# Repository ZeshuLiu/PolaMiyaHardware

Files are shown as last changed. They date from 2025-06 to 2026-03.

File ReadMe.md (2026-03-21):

# PolaMiyaHardware - 宝丽来相机改装项目

宝丽来相机自动化改装项目的机械与电路设计部分。

> 完整项目：https://github.com/ZeshuLiu/PolaMiya
> 软件固件仓库：https://github.com/ZeshuLiu/PolaMiyaSoftware

## 仓库结构

| 子目录 | 说明 |
|---|---|
| [电路/](电路/) | KiCad 电路设计 |
| [结构 Rev2N/](结构 Rev2N/) | 机械结构 3D 模型 (STL/STP) |

### 电路设计

| 模块 | 说明 |
|---|---|
| [主控器](电路/主控器/PM_Controller_R1/) | 主控制器 (STM32G474) |
| [DispKey](电路/主控器/DispKey/) | 屏幕与按键模块 |
| [电机驱动](电路/电机驱动/MotroDrive/) | 吐片电机驱动板 |
| [闪光灯转接](电路/闪光灯转接/FlashAdapter/) | 闪光灯转接板 |

> 所有 PCB 使用 **KiCad 9** 绘制，Gerber 文件和 BOM 清单位于各模块的 `production/` 子目录中。

### 结构设计

| 组件 | 说明 |
|---|---|
| 镜头总成 | Mamiya Press 127mm 镜头安装座 |
| 片仓总成 | 宝丽来相纸仓 |
| 吐片机构 | 电动吐片下巴与齿轮组 |
| 外壳 | 相机主体外壳 |
| 全息取景器 | 计划中的升级部件 |

> 所有 STL 文件位于各组件的 `STL/` 子目录中，可用 A1 mini 或 Voron0 等小型 3D 打印机打印。

## 技术栈

| 类别 | 工具/平台 |
|---|---|
| **PCB 设计** | KiCad 9 |
| **结构设计** | SolidWorks / 兼容 CAD 软件 |
| **固件** | STM32CubeMX + HAL 库，Keil MDK-ARM |
| **3D 打印** | PLA/PETG，A1 mini / Voron0 |

## 采购清单

主要采购件：
- Mamiya Press 127mm 镜头（不需要调焦桶）
- 宝丽来 AF5000（用于拆解吐片下巴、吐片电机和齿轮组）

## 使用方法

### 相机操作
- **开机/关机**：长按机身左下角按钮 2 秒
- **吐片**：三向按钮长按中键 2 秒启动吐片电机，短按中键停止，随后推动侧面推杆吐出相纸
- **测距**：开机即运行

### 功能
- ✅ 电动吐片
- ✅ 电子测距
- 🔄 自动对焦（计划中）
- 🔄 测光（计划中）
- 🔄 全息取景器（计划中）

## 已知问题

| 问题 | 状态 |
|---|---|
| 吐片口密封性能不好，严禁在有相纸的情况下打开片仓 | 使用中注意 |

## 已修复问题

| 问题 | 修复版本 |
|---|---|
| 吐片电机运行导致测距停止（硬件干扰） | Rev1.2 |
| 温度传感器位置不合理，受芯片发热影响大 | Rev1.2 |

## 相关资源

- [样片与演示]() - 待更新
- [装配指南](结构 Rev2N/) - 参考总装配 STEP 文件

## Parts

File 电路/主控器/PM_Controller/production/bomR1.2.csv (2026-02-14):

Designator | Footprint | Quantity | Value | LCSC Part #
BT1 | cr1220 | 1 | Battery_Cell
C1, C2, C25, C3 | 603 | 4 | 5pf
C10, C32, C34, C35 | 603 | 4 | 1uf
C11, C38, C5, C6 | CP_EIA-3528-21_Kemet-B_Pad1.50x2.35mm_HandSolder | 4 | 22uf
C12 | 1206 | 1 | 22uf
C14, C24 | CP_EIA-3528-21_Kemet-B_Pad1.50x2.35mm_HandSolder | 2 | 47uf
C17, C18, C19, C20 | 603 | 4 | 22uf
C21, C23, C26, C28, C29, C30, C31, C33, C36, C37, C4, C7 | 603 | 12 | 100nf
C22, C27, C8 | 603 | 3 | 10uf
C39 | CP_EIA-3528-21_Kemet-B_HandSolder | 1 | 22uf
C40 | 1206 | 1 | 1uf
C41 | 1206 | 1 | 10uf
CHG1, PW_LED1 | 805 | 2 | LED
D1 | D_SMA | 1 | SS34
D3 | D_SMA_Handsoldering | 1 | SS32
D4 | D_SOD-323_HandSoldering | 1 | 1N5819WS
FB1 | 805 | 1 | FerriteBead
FLASH1 | SolderWire-0.1sqmm_1x02_P3.6mm_D0.4mm_OD1mm_Relief | 1 | Conn_01x02_Pin
J1, J4 | JST_PH_S4B-PH-K_1x04_P2.00mm_Horizontal | 2 | Conn_01x04_Socket
J10, J7 | PinHeader_2x04_P1.27mm_Vertical | 2 | Conn_02x04_Odd_Even
J11 | PinHeader_2x06_P1.27mm_Vertical | 1 | Conn_02x06_Odd_Even
J2, J3, J9 | PinHeader_1x04_P2.54mm_Vertical | 3 | Conn_01x04_Socket
J5 | SolderWire-0.5sqmm_1x02_P4.8mm_D0.9mm_OD2.3mm | 1 | Conn_01x02_Pin
J6 | PinSocket_1x02_P2.00mm_Vertical | 1 | Conn_01x02_Pin
J8 | PinHeader_1x04_P2.00mm_Vertical | 1 | Conn_01x04_Pin
L1, L2, L3 | L_APV_APH0650 | 3 | 4.7uH
Q2, Q3, Q5, Q6 | SOT-23 | 4 | AO3400A
R1, R12, R14, R15, R2, R23, R24, R27, R28, R31, R39, R41, R42, R8 | 603 | 14 | 100k
R13, R4 | 603 | 2 | 1.5k
R16, R17, R18, R20, R21, R22 | 603 | 6 | 100k(NC)
R25, R26, R32, R40, R6 | 603 | 5 | 1k
R29, R33, R34, R35, R36, R45, R7 | 603 | 7 | 10k
R3 | 603 | 1 | RPORG(1k)
R30, R38, R43 | 603 | 3 | 150k
R37, R5 | 603 | 2 | 22k
R44 | 603 | 1 | 33k
U1, U9 | SOIC-8_3.9x4.9mm_P1.27mm | 2 | AT24CS08-SSHM
U10 | SOT-563 | 1 | TMP102xxDRL
U11, U6 | DBV0006A_TEX | 2 | TPS2552DDBVR
U12 | MFSOP6-4_4.4x3.6mm_P1.27mm | 1 | TLP127
U13 | SOT-23-6_DBV_TEX | 1 | TLV61048DBVR
U2 | SOT-223-3_TabPin2 | 1 | AMS1117-3.3
U3 | LQFP-64_10x10mm_P0.5mm | 1 | STM32G431RBTx
U5 | SOT-23-6_Handsoldering | 1 | BQ21040DBV
U7 | TSSOP-14_4.4x5mm_P0.65mm | 1 | STM32L011D4Px
U8 | SOT-23-5_HandSoldering | 1 | ME6211C25M5
Y1 | Crystal_C26-LF_D2.1mm_L6.5mm_Horizontal | 1 | 32.768kHz
Y2 | Crystal_DS26_D2.0mm_L6.0mm_Horizontal | 1 | 24Mhz

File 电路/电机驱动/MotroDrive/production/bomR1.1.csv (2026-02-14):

Designator | Footprint | Quantity | Value | LCSC Part #
C1 | 1206 | 1 | 10uf
C2 | 1206 | 1 | 1uf
C4 | CP_Elec_6.3x7.7 | 1 | 100uf
D1, D4 | D_SOD-323_HandSoldering | 2 | 1N5819WS
D3 | 805 | 1 | LED
FB1 | 603 | 1 | FerriteBead
J1 | JST_PH_S4B-PH-SM4-TB_1x04-1MP_P2.00mm_Horizontal | 1 | Conn_01x04_MountingPin
J2 | JST_PH_S2B-PH-SM4-TB_1x02-1MP_P2.00mm_Horizontal | 1 | Conn_01x02_MountingPin
L2 | L_APV_APH1265 | 1 | 4.7uH
Q1 | SOT-23 | 1 | AO3400A
R1 | 603 | 1 | 330k
R2 | 603 | 1 | 51k
R4 | 603 | 1 | 10k
R5 | 603 | 1 | 1k
U1 | SOT-23-6_DBV_TEX | 1 | TLV61048DBVR

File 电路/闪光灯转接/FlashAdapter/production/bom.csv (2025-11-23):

Designator | Footprint | Quantity | Value | LCSC Part #
J1 | SolderWire-0.75sqmm_1x02_P7mm_D1.25mm_OD3.5mm | 1 | Conn_01x02_Socket
U1 | PJ-218X-SMT | 1 | ~

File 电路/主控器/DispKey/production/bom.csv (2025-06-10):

Designator | Footprint | Quantity | Value | LCSC Part #
C1, C2 | 0805 | 2 | 10uf
C10, C11, C12 | 0603 | 3 | 1uF
D1, D2 | 0805 | 2 | LED
J1 | SolderWire-0.1sqmm_1x02_P3.6mm_D0.4mm_OD1mm | 1 | Conn_01x02_Pin
J10, J7 | PinHeader_2x04_P1.27mm_Vertical | 2 | Conn_02x04_Odd_Even
J2 | SolderWire-0.1sqmm_1x03_P3.6mm_D0.4mm_OD1mm | 1 | Conn_01x03_Pin
LCD1 | LCD1.69_240_280 | 1 | ~
R1 | 0603 | 1 | 10k
R11, R12, R13 | 0603 | 3 | 100k
SW1 | sw_push_5.8x5.8mm | 1 | ~
SW3 | Direction3 Pin5 | 1 | ~
TP1 | TestPoint_Pad_2.0x2.0mm | 1 | KEY3

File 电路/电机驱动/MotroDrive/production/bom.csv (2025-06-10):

Designator | Footprint | Quantity | Value | LCSC Part #
C1 | 1206 | 1 | 10uf
C2 | 1206 | 1 | 1uf
C3, C4 | CP_Elec_6.3x7.7 | 2 | 100uf
D1, D4 | D_SOD-323_HandSoldering | 2 | 1N5819WS
D2, D3 | 0805 | 2 | LED
J1 | JST_PH_S4B-PH-SM4-TB_1x04-1MP_P2.00mm_Horizontal | 1 | Conn_01x04_MountingPin
J2 | JST_PH_S2B-PH-SM4-TB_1x02-1MP_P2.00mm_Horizontal | 1 | Conn_01x02_MountingPin
L2 | L_APV_APH1265 | 1 | 4.7uH
R1 | 0603 | 1 | 330k
R2 | 0603 | 1 | 51k
R3, R4 | 0603 | 2 | 10k
U1 | SOT-23-6_DBV_TEX | 1 | TLV61048DBVR

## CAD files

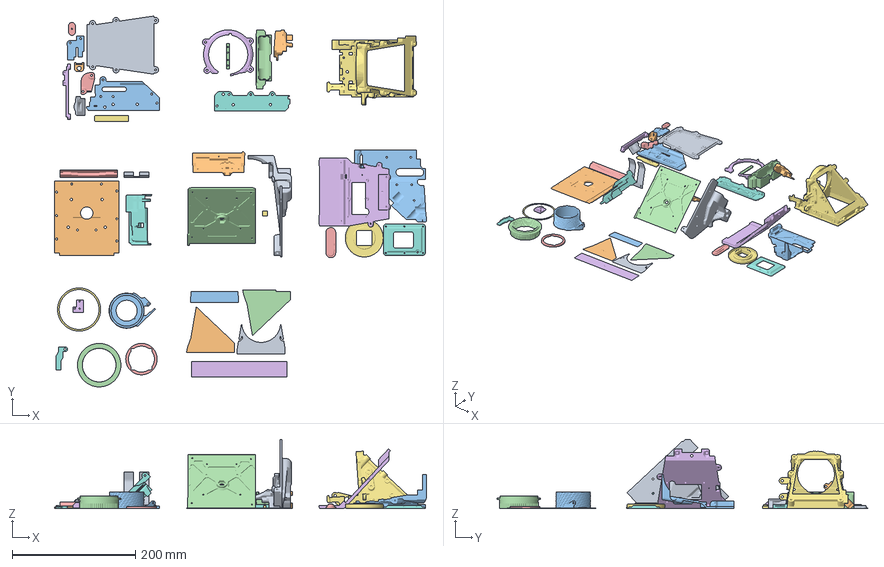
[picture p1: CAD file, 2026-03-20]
结构Rev2N/PolaMiya_FullAssemble.3mf
602.8 x 600.9 x 112.5 mm
反光镜盖板.STL
前左盖.STL
右侧板.STL
后侧板.STL
齿轮盖.STL
调焦桶盖.STL
出片推杆.STL
左侧板.STL
齿轮维护盖.STL
电机卡环.STL
推杆外框.STL
推片钩衬垫.STL
推片把手.STL
电池压板.STL
主片仓.STL
前盖板.STL
片仓弹簧.STL
底板.STL
右侧壳.STL
底壳.STL
推片杆外罩.STL
背壳.STL
镜头挡光板.STL
屏幕盖.STL
左侧壳.STL
顶壳.STL
MamiyaPressLensSeat.STL
内环.STL
挡板.STL
滑块连接.STL
镜头衬垫.STL
闪光灯线.STL
前侧.STL
右内壁.STL
后侧.STL
左内壁.STL
齿轮定位.STL
镜筒.STL
按钮.STL

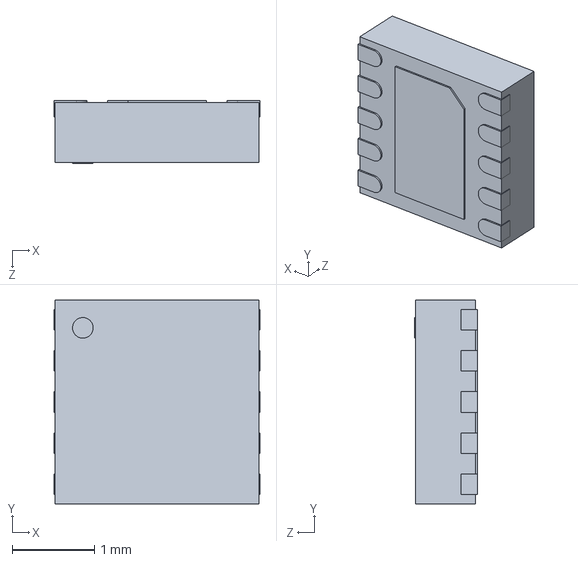
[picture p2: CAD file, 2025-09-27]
结构Rev2N/电路/机身主控/CQ assembly.SLDPRT
2.50 x 2.47 x 0.76 mm

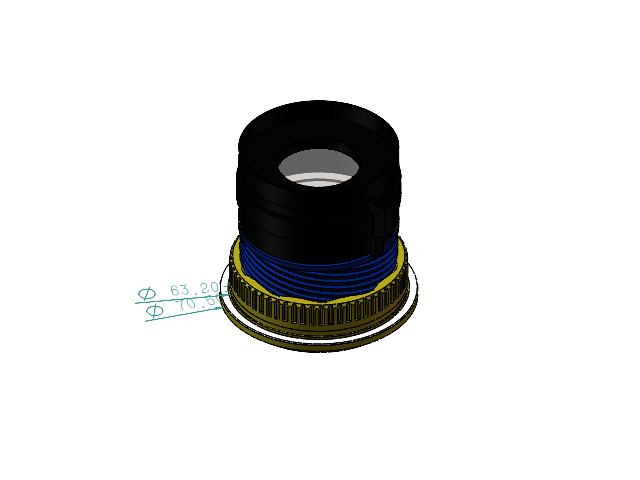
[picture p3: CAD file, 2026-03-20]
结构Rev2N/镜头总成/镜头总成.SLDASM
内环
MamiyaPressLensSeat
滑块连接
MamiyaPress127
MGN7C
镜头衬垫

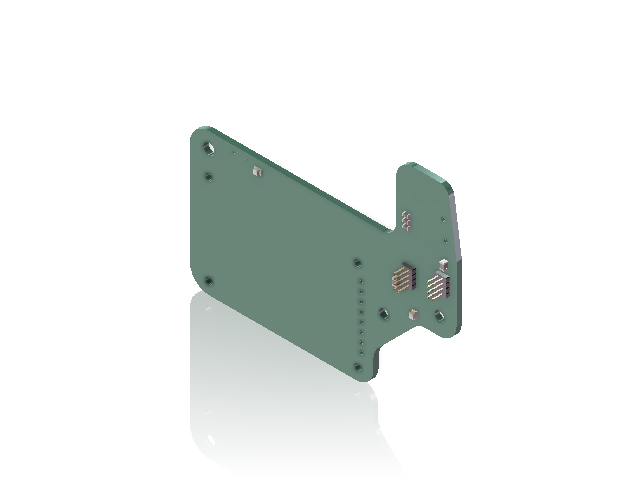
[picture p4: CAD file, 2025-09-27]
结构Rev2N/电路/DispKey_R1_0/DispKey_Screen_R1_0.SLDASM
LED_0805_2012Metric x 2
C_0805_2012Metric x 2
C_0603_1608Metric x 3
PinHeader_2x04_P1.27mm_Vertical x 2
R_0603_1608Metric x 4
DispKey_PCB

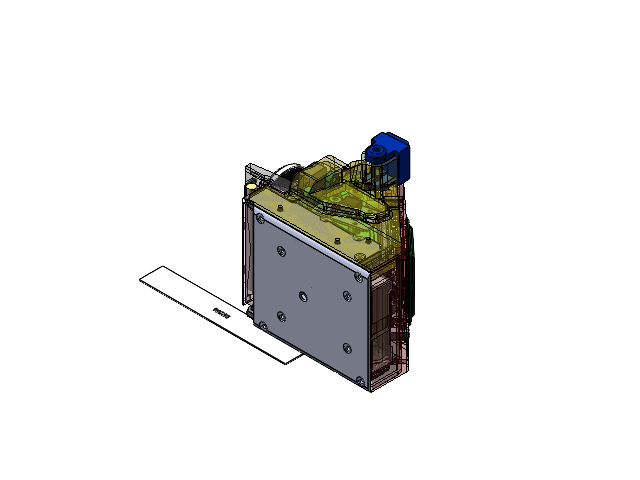
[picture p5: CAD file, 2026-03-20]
结构Rev2N/装配.SLDASM
主片仓
主反射镜
相纸盒
吐片口机身钣金-拆机
MG825-拆机
1.6x20.6-拆机
齿轮A-拆机
1.6x14.6-拆机
齿轮B-拆机
齿轮C-拆机
齿轮D-拆机
齿轮E-拆机
PinHeader_2x04_P1.27mm_Vertical.step x 2
R_0603_1608Metric.step x 42
C_0603_1608Metric.step x 30
SOT-23.step x 6
LQFP-64_10x10mm_P0.5mm.step
PinHeader_1x04_P2.00mm_Vertical.step
PinHeader_2x06_P1.27mm_Vertical.step
CP_EIA-3528-21_Kemet-B.step x 8
PinHeader_1x04_P2.54mm_Vertical.step x 3
LED_0805_2012Metric.step x 2
SOIC-8_3.9x4.9mm_P1.27mm.step x 2
SOT-23-6.step
JST_PH_S4B-PH-K_1x04_P2.00mm_Horizontal.step x 2
D_SMA.step x 3
SOT-563.step
Crystal_C26-LF_D2.1mm_L6.5mm_Horizontal.step x 3
SOT-223.step
PinSocket_1x02_P2.00mm_Vertical.step
L_APV_ANR5040.step
VSSOP-8_3x3mm_P0.65mm.step
TSSOP-14_4.4x5mm_P0.65mm.step
SOT-23-5.step
MFSOP6-4_4.4x3.6mm_P1.27mm.step
L_0805_2012Metric.step
PM_Controller_PCB.step
反光镜盖板
推片勾
MGN7导轨1
调焦桶盖
出片推杆
推片把手
齿轮盖
推片钩衬垫
电机卡环
齿轮维护盖
右侧板
18650电池
后侧板
电池负极弹片
电池正极弹片
激光测距SDM18
D_SOD_323.step x 2
CP_Elec_63x77.step x 2
C_1206_3216Metric-0.step x 2
R_0603_1608Metric-1.step x 4
LED_0805_2012Metric-2.step x 2
L_APV_APH1265-3.step
_autosave-MotroDrive_PCB.step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

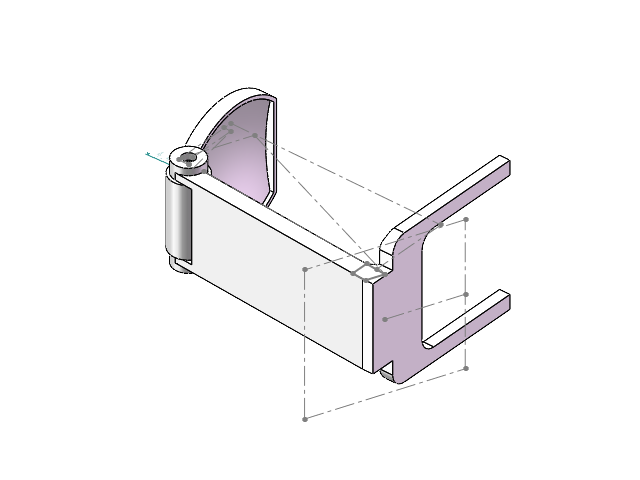
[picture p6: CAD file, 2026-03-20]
结构Rev2N/全息取景器/瞄准装置.SLDASM
主座
镜座
反射镜片

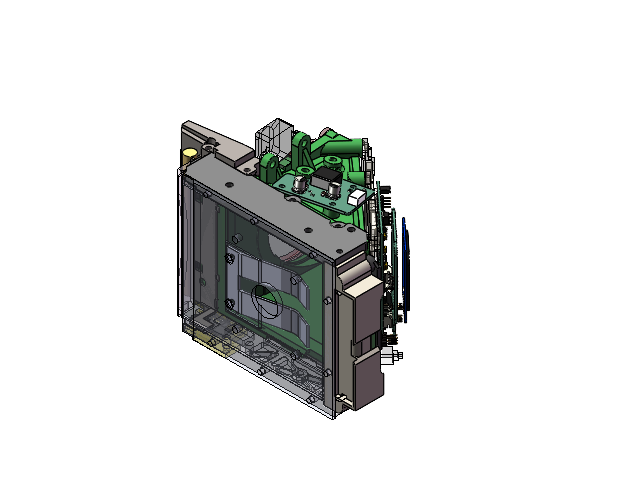
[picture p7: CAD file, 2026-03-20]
结构Rev2N/片仓总成/片仓总成.SLDASM
主片仓
主反射镜
相纸盒
吐片口机身钣金-拆机
MG825-拆机
1.6x20.6-拆机
齿轮A-拆机
1.6x14.6-拆机
齿轮B-拆机
齿轮C-拆机
齿轮D-拆机
齿轮E-拆机
PinHeader_2x04_P1.27mm_Vertical.step x 2
R_0603_1608Metric.step x 42
C_0603_1608Metric.step x 30
SOT-23.step x 6
LQFP-64_10x10mm_P0.5mm.step
PinHeader_1x04_P2.00mm_Vertical.step
PinHeader_2x06_P1.27mm_Vertical.step
CP_EIA-3528-21_Kemet-B.step x 8
PinHeader_1x04_P2.54mm_Vertical.step x 3
LED_0805_2012Metric.step x 2
SOIC-8_3.9x4.9mm_P1.27mm.step x 2
SOT-23-6.step
JST_PH_S4B-PH-K_1x04_P2.00mm_Horizontal.step x 2
D_SMA.step x 3
SOT-563.step
Crystal_C26-LF_D2.1mm_L6.5mm_Horizontal.step x 3
SOT-223.step
PinSocket_1x02_P2.00mm_Vertical.step
L_APV_ANR5040.step
VSSOP-8_3x3mm_P0.65mm.step
TSSOP-14_4.4x5mm_P0.65mm.step
SOT-23-5.step
MFSOP6-4_4.4x3.6mm_P1.27mm.step
L_0805_2012Metric.step
PM_Controller_PCB.step
反光镜盖板
推片勾
MGN7导轨1
调焦桶盖
出片推杆
推片把手
齿轮盖
推片钩衬垫
电机卡环
齿轮维护盖
右侧板
18650电池
后侧板
电池负极弹片
电池正极弹片
激光测距SDM18
D_SOD_323.step x 2
CP_Elec_63x77.step x 2
C_1206_3216Metric-0.step x 2
R_0603_1608Metric-1.step x 4
LED_0805_2012Metric-2.step x 2
L_APV_APH1265-3.step
_autosave-MotroDrive_PCB.step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

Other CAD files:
结构Rev2N/电路/机身主控/Hirose_FH12-8S-0.5SH_1x08-1MP_P0.50mm_Horizontal.SLDASM
结构Rev2N/电路/机身主控/TSSOP-14_4.4x5mm_P0.65mm.SLDASM
结构Rev2N/电路/机身主控/CP_EIA-3216-18_Kemet-A.SLDASM
结构Rev2N/电路/机身主控/Hirose_FH12-6S-0.5SH_1x06-1MP_P0.50mm_Horizontal.SLDASM
结构Rev2N/电路/机身主控/C_0805_2012Metric.SLDASM
结构Rev2N/电路/机身主控/D_SMA.SLDASM
结构Rev2N/电路/机身主控/PinHeader_1x04_P2.54mm_Vertical.SLDASM
结构Rev2N/电路/机身主控/SOT-23-6.SLDASM
结构Rev2N/电路/机身主控/R_1210_3225Metric.SLDASM
结构Rev2N/电路/机身主控/L_Cenker_CKCS6020.SLDASM
结构Rev2N/电路/机身主控/WSON-10-1EP_2.5x2.5mm_P0.5mm_EP1.2x2mm.SLDASM
电路/sdm18串口.SLDPRT
电路/闪光灯转接/FlashAdapter/FlashAdapter.step
电路/闪光灯转接/FlashAdapter/upper.SLDPRT
结构Rev2N/光学设计.SLDPRT
结构Rev2N/全息取景器/STL/主座.STL
结构Rev2N/全息取景器/STL/镜座.STL
结构Rev2N/全息取景器/主座.SLDPRT
结构Rev2N/全息取景器/反射镜片.SLDPRT
结构Rev2N/全息取景器/标靶.SLDPRT
结构Rev2N/全息取景器/镜座.SLDPRT
结构Rev2N/外壳/STL/右侧壳.STL
结构Rev2N/外壳/STL/屏幕盖.STL
结构Rev2N/外壳/STL/左侧壳.STL
结构Rev2N/外壳/STL/底壳.STL
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

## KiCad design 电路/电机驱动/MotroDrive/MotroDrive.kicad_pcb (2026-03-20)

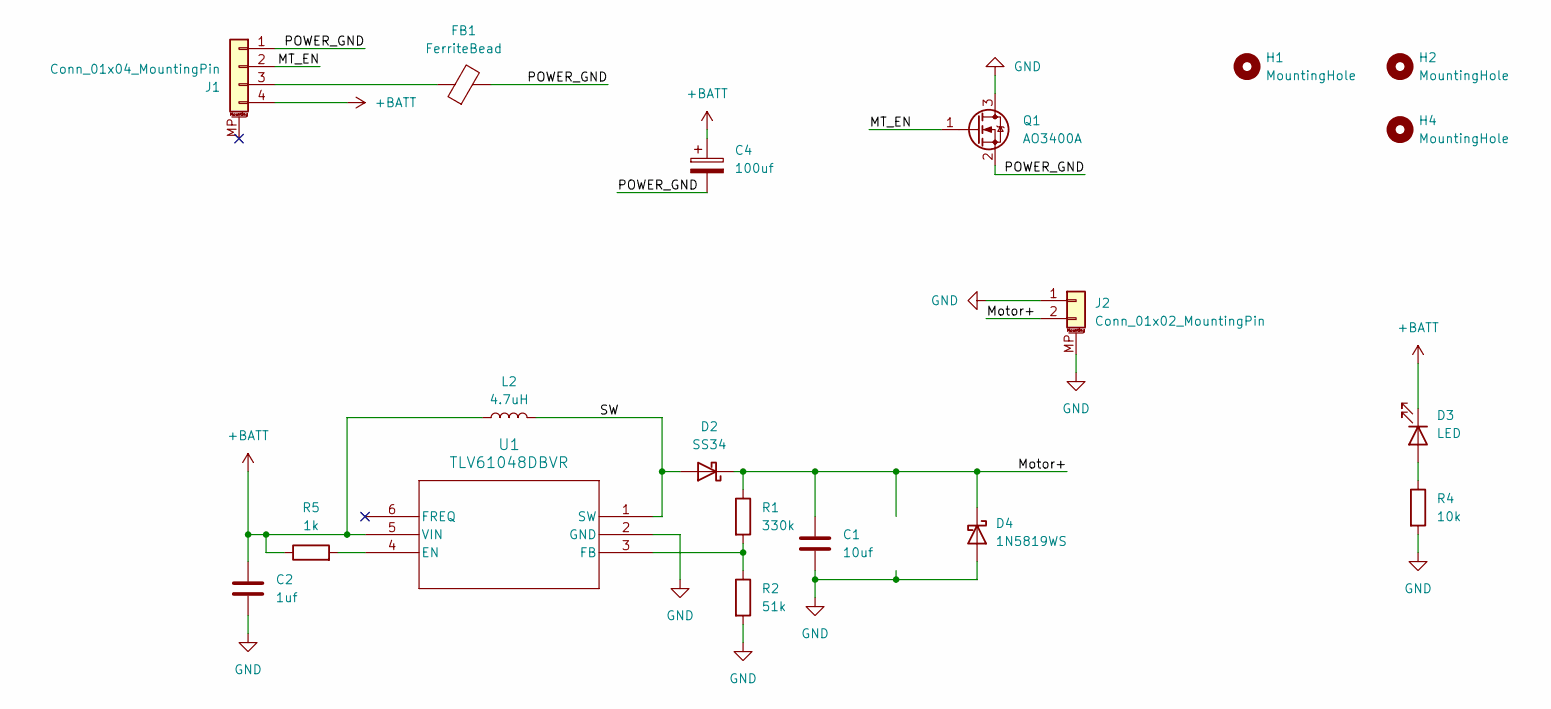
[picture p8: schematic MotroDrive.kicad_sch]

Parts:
C1: 10uf; C_1206_3216Metric_Pad1.33x1.80mm_HandSolder
C2: 1uf; C_1206_3216Metric_Pad1.33x1.80mm_HandSolder
C4: 100uf; CP_Elec_6.3x7.7
D2: SS34; D_SMA
D3: LED; LED_0805_2012Metric_Pad1.15x1.40mm_HandSolder
D4: 1N5819WS; D_SOD-323_HandSoldering
FB1: FerriteBead; L_0603_1608Metric
H1, H2, H4: MountingHole; MountingHole_3.2mm_M3
J1: Conn_01x04_MountingPin; JST_PH_S4B-PH-SM4-TB_1x04-1MP_P2.00mm_Horizontal
J2: Conn_01x02_MountingPin; JST_PH_S2B-PH-SM4-TB_1x02-1MP_P2.00mm_Horizontal
L2: 4.7uH; L_APV_APH1265
Q1: AO3400A; SOT-23
R1: 330k; R_0603_1608Metric_Pad0.98x0.95mm_HandSolder
R2: 51k; R_0603_1608Metric_Pad0.98x0.95mm_HandSolder
R4: 10k; R_0603_1608Metric_Pad0.98x0.95mm_HandSolder
R5: 1k; R_0603_1608Metric
U1: TLV61048DBVR; SOT-23-6_DBV_TEX

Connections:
+BATT: C2.1, C4.1, D3.1 (K), J1.4, L2.1, R5.1, U1.5 (VIN)
/MT_EN: J1.2, Q1.1 (G)
/Motor+: C1.1, D2.1 (K), D4.1 (K), J2.2, R1.1
/POWER_GND: C4.2, FB1.2, J1.1, Q1.2 (S)
/SW: D2.2 (A), L2.2, U1.1 (SW)
GND: C1.2, C2.2, D4.2 (A), J2.1, J2.MP (MountPin), Q1.3 (D), R2.2, R4.2, U1.2 (GND)
unnamed: D3.2 (A), R4.1
unnamed: FB1.1, J1.3
unnamed: R5.2, U1.4 (EN)
unnamed: R1.2, R2.1, U1.3 (FB)

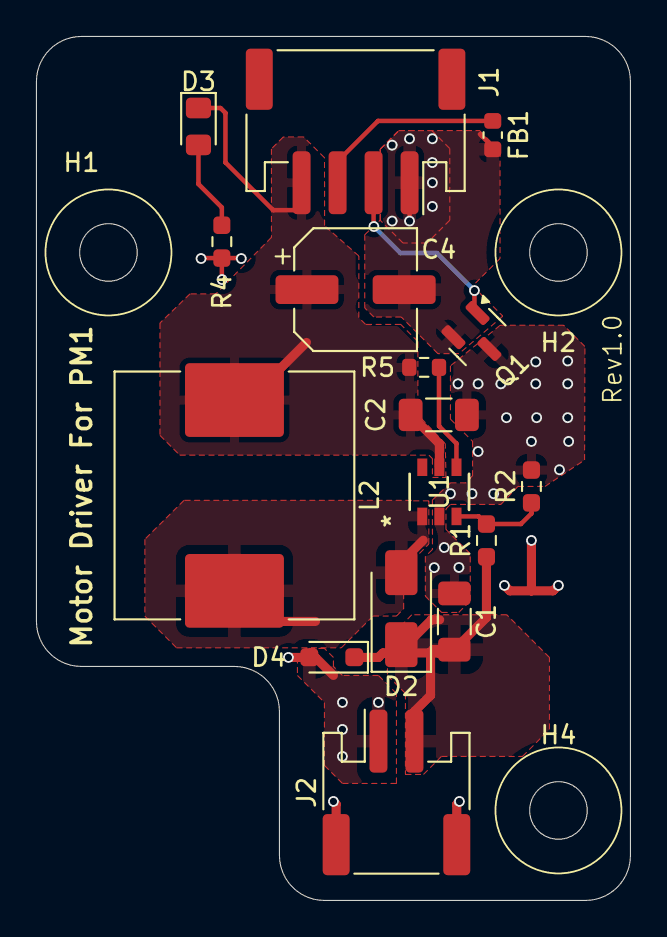
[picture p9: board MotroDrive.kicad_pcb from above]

Board: 2 copper layers, 33.0 x 48.0 mm, 19 parts (0 on the bottom side), 10 nets.

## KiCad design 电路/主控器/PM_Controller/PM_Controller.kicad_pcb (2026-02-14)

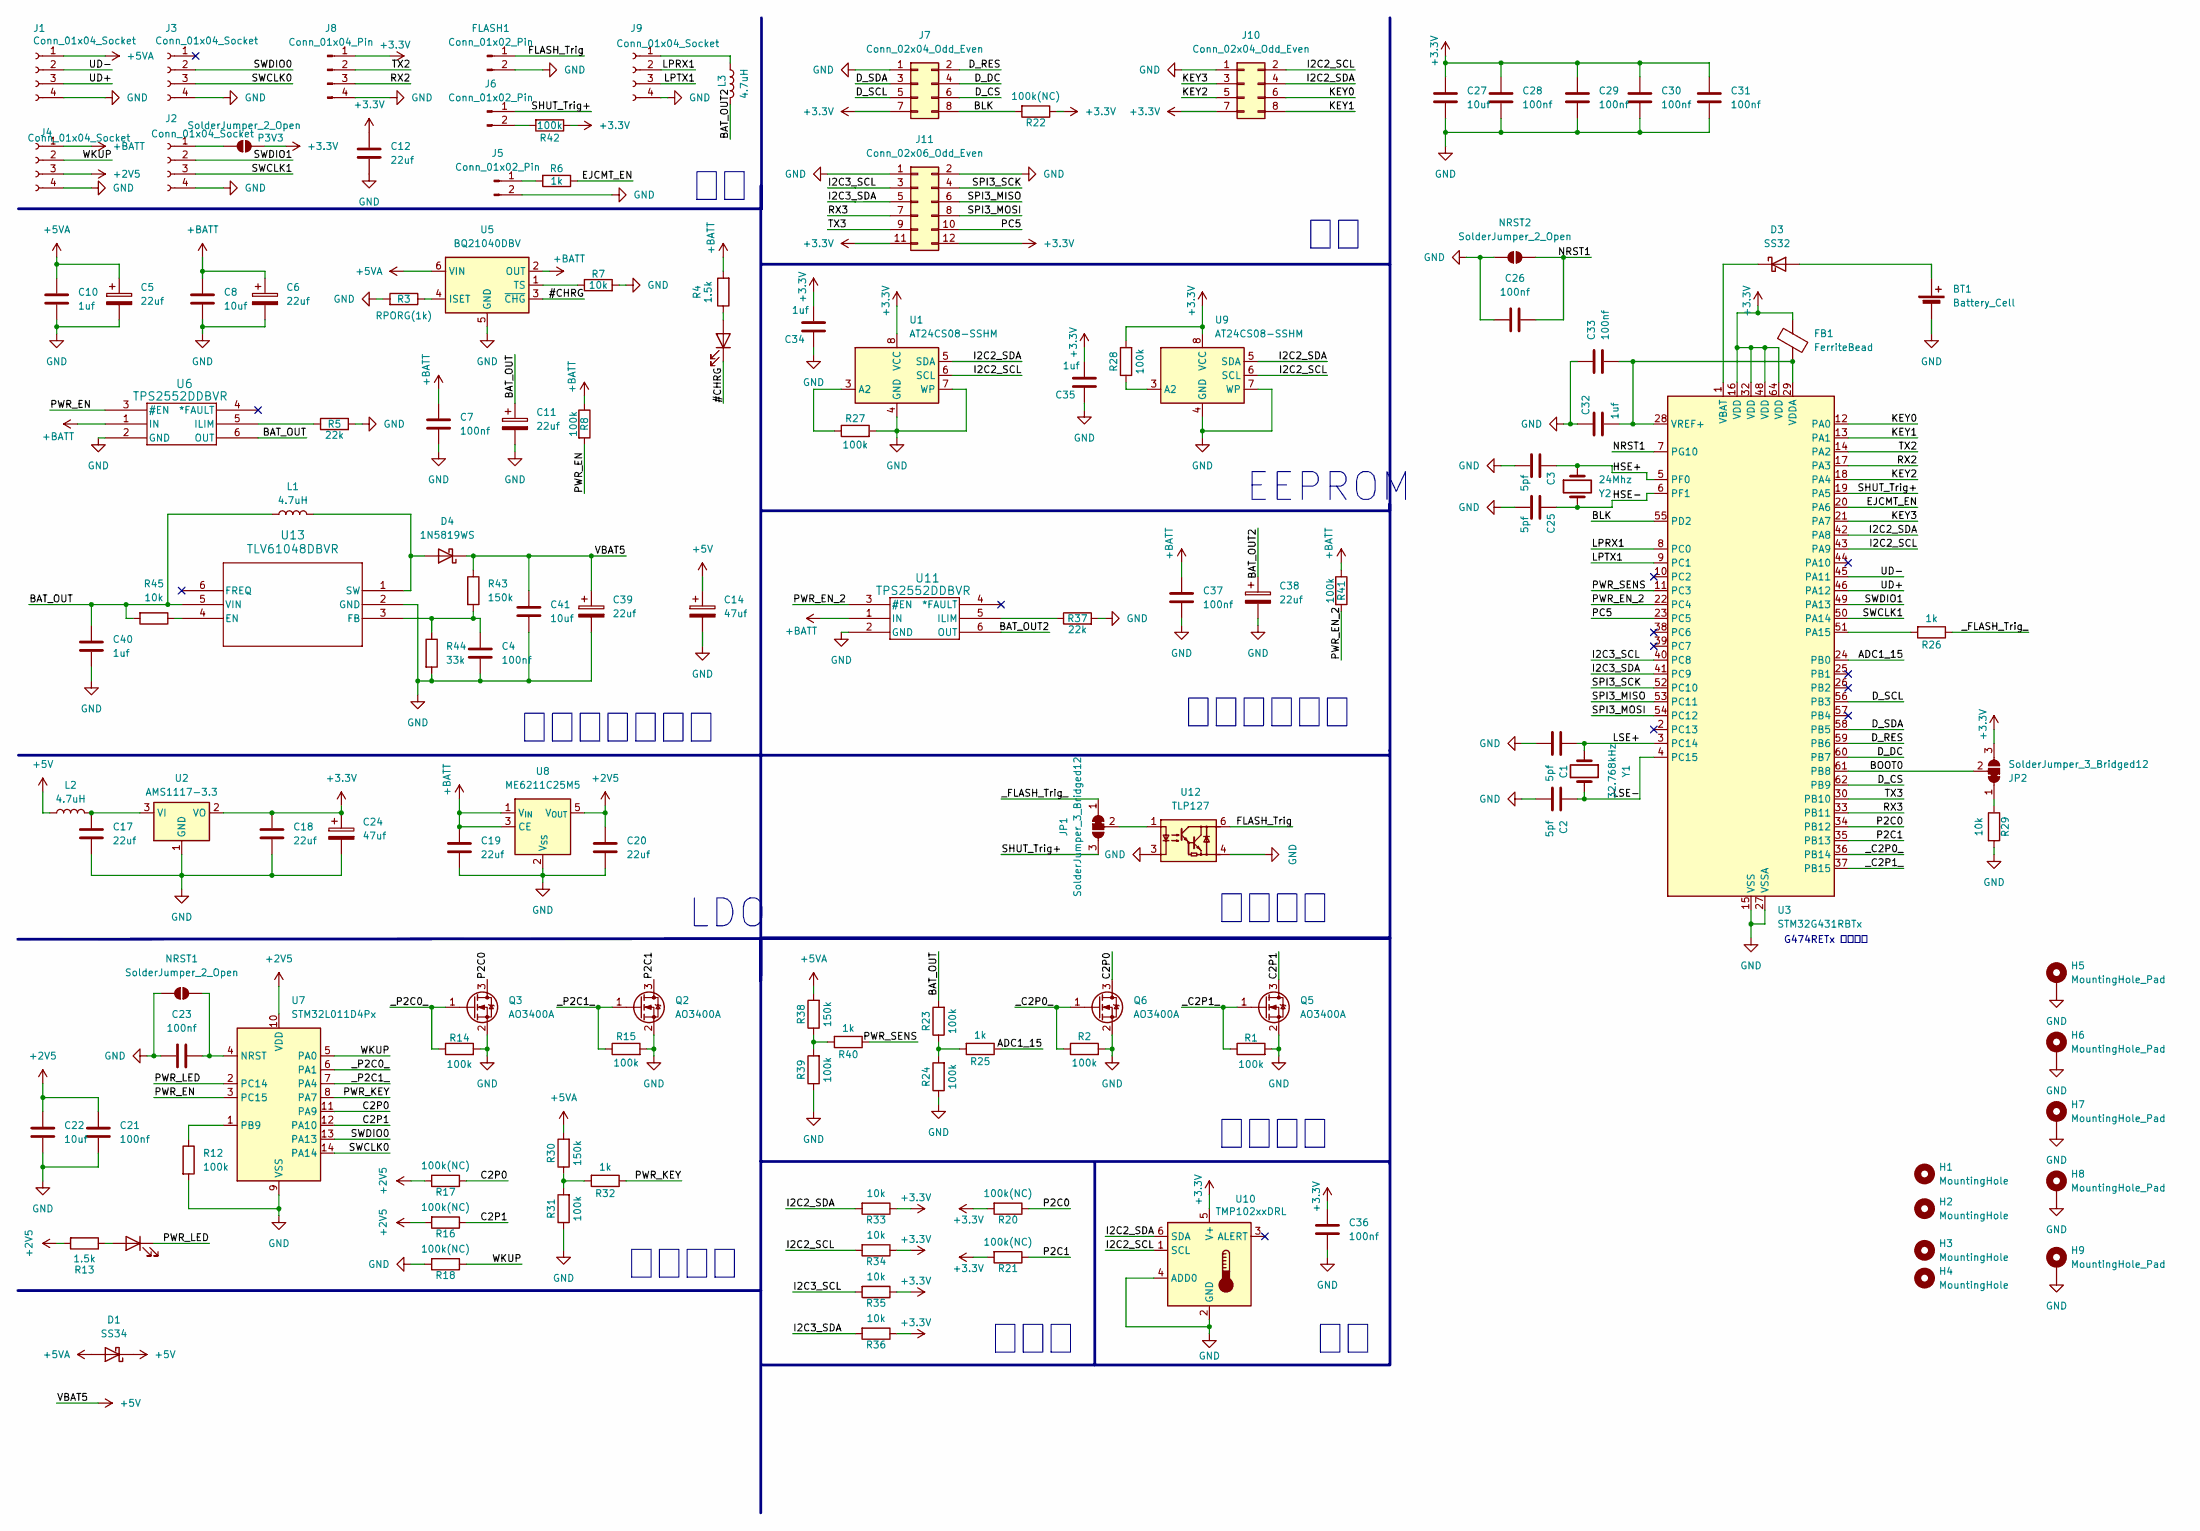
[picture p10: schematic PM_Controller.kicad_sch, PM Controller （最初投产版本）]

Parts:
BT1: Battery_Cell; cr1220
C1, C2, C3, C25: 5pf; C_0603_1608Metric_Pad1.08x0.95mm_HandSolder
C4: 100nf; C_0603_1608Metric
C5, C6, C11, C38: 22uf; CP_EIA-3528-21_Kemet-B_Pad1.50x2.35mm_HandSolder
C7, C21, C23, C26, C28, C29, C30, C31, C33, C36, C37: 100nf; C_0603_1608Metric_Pad1.08x0.95mm_HandSolder
C8, C22, C27: 10uf; C_0603_1608Metric_Pad1.08x0.95mm_HandSolder
C10, C32, C34, C35: 1uf; C_0603_1608Metric_Pad1.08x0.95mm_HandSolder
C12: 22uf; C_1206_3216Metric_Pad1.33x1.80mm_HandSolder
C14, C24: 47uf; CP_EIA-3528-21_Kemet-B_Pad1.50x2.35mm_HandSolder
C17, C18, C19, C20: 22uf; C_0603_1608Metric_Pad1.08x0.95mm_HandSolder
C39: 22uf; CP_EIA-3528-21_Kemet-B_HandSolder
C40: 1uf; C_1206_3216Metric_Pad1.33x1.80mm_HandSolder
C41: 10uf; C_1206_3216Metric_Pad1.33x1.80mm_HandSolder
CHG1: LED; LED_0805_2012Metric_Pad1.15x1.40mm_HandSolder
D1: SS34; D_SMA
D3: SS32; D_SMA_Handsoldering
D4: 1N5819WS; D_SOD-323_HandSoldering
FB1: FerriteBead; L_0805_2012Metric_Pad1.05x1.20mm_HandSolder
FLASH1: Conn_01x02_Pin; SolderWire-0.1sqmm_1x02_P3.6mm_D0.4mm_OD1mm_Relief
H1, H2, H3, H4: MountingHole; MountingHole_3.2mm_M3
H5, H6, H7, H8, H9: MountingHole_Pad; MountingHole_3.2mm_M3_DIN965_Pad_TopBottom
J1, J4: Conn_01x04_Socket; JST_PH_S4B-PH-K_1x04_P2.00mm_Horizontal
J2, J3, J9: Conn_01x04_Socket; PinHeader_1x04_P2.54mm_Vertical
J5: Conn_01x02_Pin; SolderWire-0.5sqmm_1x02_P4.8mm_D0.9mm_OD2.3mm
J6: Conn_01x02_Pin; PinSocket_1x02_P2.00mm_Vertical
J7, J10: Conn_02x04_Odd_Even; PinHeader_2x04_P1.27mm_Vertical
J8: Conn_01x04_Pin; PinHeader_1x04_P2.00mm_Vertical
J11: Conn_02x06_Odd_Even; PinHeader_2x06_P1.27mm_Vertical
JP1, JP2: SolderJumper_3_Bridged12; SolderJumper-3_P1.3mm_Bridged12_Pad1.0x1.5mm
L1, L2, L3: 4.7uH; L_APV_APH0650
NRST1, NRST2: SolderJumper_2_Open; SolderJumper-2_P1.3mm_Open_RoundedPad1.0x1.5mm
P3V3: SolderJumper_2_Open; SolderJumper-2_P1.3mm_Open_RoundedPad1.0x1.5mm
PW_LED1: LED; LED_0805_2012Metric_Pad1.15x1.40mm_HandSolder
Q2, Q3, Q5, Q6: AO3400A; SOT-23
R1, R2, R8, R12, R14, R15, R23, R24, R27, R28, R31, R39, R41, R42: 100k; R_0603_1608Metric_Pad0.98x0.95mm_HandSolder
R3: RPORG(1k); R_0603_1608Metric_Pad0.98x0.95mm_HandSolder
R4, R13: 1.5k; R_0603_1608Metric_Pad0.98x0.95mm_HandSolder
R5, R37: 22k; R_0603_1608Metric_Pad0.98x0.95mm_HandSolder
R6, R25, R26, R32, R40: 1k; R_0603_1608Metric_Pad0.98x0.95mm_HandSolder
R7, R29, R33, R34, R35, R36, R45: 10k; R_0603_1608Metric_Pad0.98x0.95mm_HandSolder
R16, R17, R18, R20, R21, R22: 100k(NC); R_0603_1608Metric_Pad0.98x0.95mm_HandSolder
R30, R38, R43: 150k; R_0603_1608Metric_Pad0.98x0.95mm_HandSolder
R44: 33k; R_0603_1608Metric_Pad0.98x0.95mm_HandSolder
U1, U9: AT24CS08-SSHM; SOIC-8_3.9x4.9mm_P1.27mm
U2: AMS1117-3.3; SOT-223-3_TabPin2
U3: STM32G431RBTx; LQFP-64_10x10mm_P0.5mm
U5: BQ21040DBV; SOT-23-6_Handsoldering
U6, U11: TPS2552DDBVR; DBV0006A_TEX
U7: STM32L011D4Px; TSSOP-14_4.4x5mm_P0.65mm
U8: ME6211C25M5; SOT-23-5_HandSoldering
U10: TMP102xxDRL; SOT-563
U12: TLP127; MFSOP6-4_4.4x3.6mm_P1.27mm
U13: TLV61048DBVR; SOT-23-6_DBV_TEX
Y1: 32.768kHz; Crystal_C26-LF_D2.1mm_L6.5mm_Horizontal
Y2: 24Mhz; Crystal_DS26_D2.0mm_L6.0mm_Horizontal

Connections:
+2V5: C20.1, C21.1, C22.1, J4.3, R13.2, R16.2, R17.2, U7.10 (VDD), U8.5 (V_{OUT})
+3.3V: C12.1, C18.1, C24.1, C27.1, C28.1, C29.1, C30.1, C31.1, C34.2, C35.2, C36.2, FB1.1, J7.7, J8.1, J10.7, J11.11, J11.12, JP2.3 (B), P3V3.2 (B), R20.2, R21.2, R22.1, R28.2, R33.1, R34.1, R35.1, R36.1, R42.1, U1.8 (VCC), U2.2 (VO), U3.16 (VDD), U3.32 (VDD), U3.48 (VDD), U3.64 (VDD), U9.8 (VCC), U10.5 (V+)
+5V: C14.1, C39.1, C41.1, D1.1 (K), D4.1 (K), L2.1, R43.1
+5VA: C5.1, C10.1, D1.2 (A), J1.1, R30.2, R38.2, U5.6 (VIN)
+BATT: C6.1, C7.1, C8.1, C19.1, C37.1, J4.1, R4.2, R8.1, R41.1, U5.2 (OUT), U6.1 (IN), U8.1 (V_{IN}), U8.3 (CE), U11.1 (IN)
/#CHRG: CHG1.1 (K), U5.3 (~CHG)
/ADC1_15: R25.1, U3.24 (PB0)
/BAT_OUT: C11.1, C40.1, L1.1, R23.2, R45.2, U6.6 (OUT), U13.5 (VIN)
/BAT_OUT2: C38.1, L3.2, U11.6 (OUT)
/BLK: J7.8, R22.2, U3.55 (PD2)
/BOOT0: JP2.2 (C), U3.61 (PB8)
/C2P0: Q6.3 (D), R17.1, U7.11 (PA9)
/C2P1: Q5.3 (D), R16.1, U7.12 (PA10)
/D_CS: J7.6, U3.62 (PB9)
/D_DC: J7.4, U3.60 (PB7)
/D_RES: J7.2, U3.59 (PB6)
/D_SCL: J7.5, U3.56 (PB3)
/D_SDA: J7.3, U3.58 (PB5)
/EJCMT_EN: R6.1, U3.20 (PA6)
/FLASH_Trig: FLASH1.1, U12.6
/HSE+: C3.1, U3.5 (PF0), Y2.1
/HSE-: C25.1, U3.6 (PF1), Y2.2
/I2C2_SCL: J10.2, R34.2, U1.6 (SCL), U3.43 (PA9), U9.6 (SCL), U10.1 (SCL)
/I2C2_SDA: J10.4, R33.2, U1.5 (SDA), U3.42 (PA8), U9.5 (SDA), U10.6 (SDA)
/I2C3_SCL: J11.3, R35.2, U3.40 (PC8)
/I2C3_SDA: J11.5, R36.2, U3.41 (PC9)
/KEY0: J10.6, U3.12 (PA0)
/KEY1: J10.8, U3.13 (PA1)
/KEY2: J10.5, U3.18 (PA4)
/KEY3: J10.3, U3.21 (PA7)
/LPRX1: J9.2, U3.8 (PC0)
/LPTX1: J9.3, U3.9 (PC1)
/LSE+: C1.1, U3.3 (PC14), Y1.1
/LSE-: C2.1, U3.4 (PC15), Y1.2
/NRST1: C26.2, NRST2.2 (B), U3.7 (PG10)
/P2C0: Q3.3 (D), R20.1, U3.34 (PB12)
/P2C1: Q2.3 (D), R21.1, U3.35 (PB13)
/PC5: J11.10, U3.23 (PC5)
/PWR_EN: R8.2, U6.3 (#EN), U7.3 (PC15)
/PWR_EN_2: R41.2, U3.22 (PC4), U11.3 (#EN)
/PWR_KEY: R32.1, U7.8 (PA7)
/PWR_LED: PW_LED1.1 (K), U7.2 (PC14)
/PWR_SENS: R40.1, U3.11 (PC3)
/RX2: J8.3, U3.17 (PA3)
/RX3: J11.7, U3.33 (PB11)
/SHUT_Trig+: J6.1, JP1.3 (B), U3.19 (PA5)
/SPI3_MISO: J11.6, U3.53 (PC11)
/SPI3_MOSI: J11.8, U3.54 (PC12)
/SPI3_SCK: J11.4, U3.52 (PC10)
/SWCLK0: J3.3, U7.14 (PA14)
/SWCLK1: J2.3, U3.50 (PA14)
/SWDIO0: J3.2, U7.13 (PA13)
/SWDIO1: J2.2, U3.49 (PA13)
/TX2: J8.2, U3.14 (PA2)
/TX3: J11.9, U3.30 (PB10)
/UD+: J1.3, U3.46 (PA12)
/UD-: J1.2, U3.45 (PA11)
/WKUP: J4.2, R18.1, U7.5 (PA0)
/_C2P0_: Q6.1 (G), R2.1, U3.36 (PB14)
/_C2P1_: Q5.1 (G), R1.1, U3.37 (PB15)
/_FLASH_Trig_: JP1.1 (A), R26.1
/_P2C0_: Q3.1 (G), R14.1, U7.6 (PA1)
/_P2C1_: Q2.1 (G), R15.1, U7.7 (PA4)
GND: BT1.2 (-), C1.2, C2.2, C3.2, C4.2, C5.2, C6.2, C7.2, C8.2, C10.2, C11.2, C12.2, C14.2, C17.2, C18.2, C19.2, C20.2, C21.2, C22.2, C23.1, C24.2, C25.2, C26.1, C27.2, C28.2, C29.2, C30.2, C31.2, C32.1, C33.1, C34.1, C35.1, C36.1, C37.2, C38.2, C39.2, C40.2, C41.2, FLASH1.2, H5.1, H6.1, H7.1, H8.1, H9.1, J1.4, J2.4, J3.4, J4.4, J5.2, J7.1, J8.4, J9.4, J10.1, J11.1, J11.2, NRST1.1 (A), NRST2.1 (A), Q2.2 (S), Q3.2 (S), Q5.2 (S), Q6.2 (S), R1.2, R2.2, R3.2, R5.2, R7.2, R12.2, R14.2, R15.2, R18.2, R24.1, R27.2, R29.2, R31.1, R37.2, R39.1, R44.2, U1.4 (GND), U1.7 (WP), U2.1 (GND), U3.15 (VSS), U3.27 (VSSA), U3.31 (VSS), U3.47 (VSS), U3.63 (VSS), U5.5 (GND), U6.2 (GND), U7.9 (VSS), U8.2 (V_{SS}), U9.4 (GND), U9.7 (WP), U10.2 (GND), U10.4 (ADD0), U11.2 (GND), U12.3, U12.4, U13.2 (GND)
unnamed: BT1.1 (+), D3.2 (A)
unnamed: CHG1.2 (A), R4.1
unnamed: D3.1 (K), U3.1 (VBAT)
unnamed: D4.2 (A), L1.2, U13.1 (SW)
unnamed: J2.1, P3V3.1 (A)
unnamed: J5.1, R6.2
unnamed: J6.2, R42.2
unnamed: J9.1, L3.1
unnamed: JP1.2 (C), U12.1
unnamed: JP2.1 (A), R29.1
unnamed: C23.2, NRST1.2 (B), U7.4 (NRST)
unnamed: PW_LED1.2 (A), R13.1
unnamed: R23.1, R24.2, R25.2
unnamed: R30.1, R31.2, R32.2
unnamed: R38.1, R39.2, R40.2
unnamed: R27.1, U1.3 (A2)
unnamed: C17.1, L2.2, U2.3 (VI)
unnamed: R26.2, U3.51 (PA15)
unnamed: C32.2, C33.2, FB1.2, U3.28 (VREF+), U3.29 (VDDA)
unnamed: R3.1, U5.4 (ISET)
unnamed: R7.1, U5.1 (TS)
unnamed: R5.1, U6.5 (ILIM)
unnamed: R12.1, U7.1 (PB9)
unnamed: R28.1, U9.3 (A2)
unnamed: R37.1, U11.5 (ILIM)
unnamed: R45.1, U13.4 (EN)
unnamed: C4.1, R43.2, R44.1, U13.3 (FB)

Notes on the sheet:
EEPROM
电源管理
接口电平
上下拉
G474RETx 应该可用
相机功能
LDO
电池充电、升压
预留电源输出

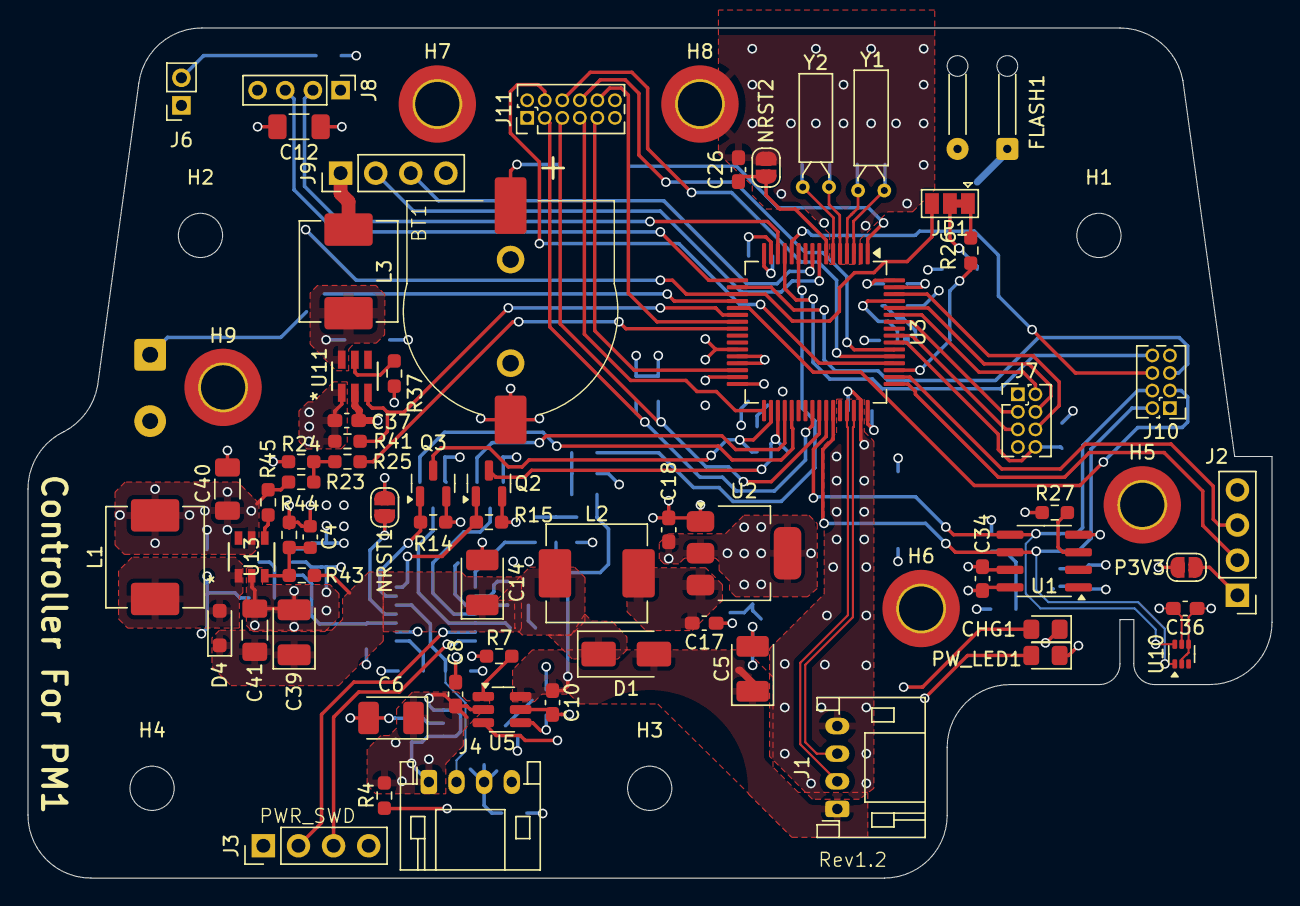
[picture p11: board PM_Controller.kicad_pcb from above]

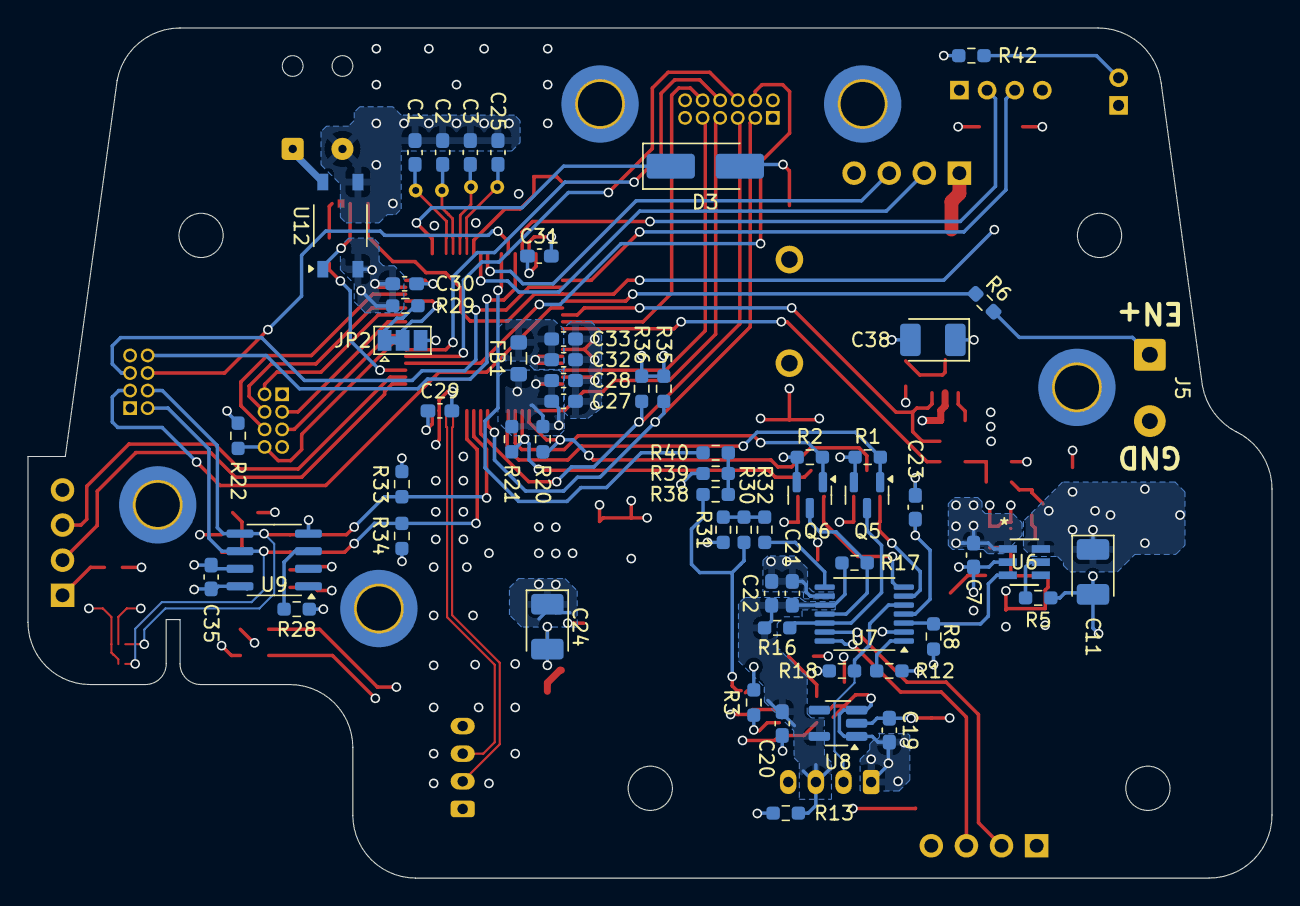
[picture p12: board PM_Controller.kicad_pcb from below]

Board: 4 copper layers, 90.0 x 61.5 mm, 132 parts (59 on the bottom side), 91 nets.

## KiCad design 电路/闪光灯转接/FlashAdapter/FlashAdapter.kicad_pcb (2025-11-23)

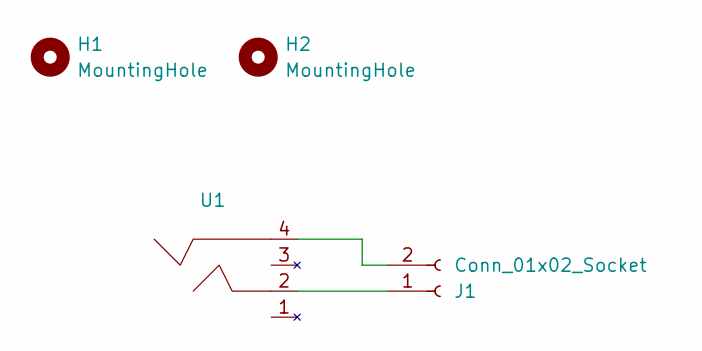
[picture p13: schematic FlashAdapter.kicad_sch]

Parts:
H1, H2: MountingHole; MountingHole_2.7mm_M2.5
J1: Conn_01x02_Socket; SolderWire-0.75sqmm_1x02_P7mm_D1.25mm_OD3.5mm
U1: PJ-218X-SMT

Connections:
unnamed: J1.1, U1.2
unnamed: J1.2, U1.4

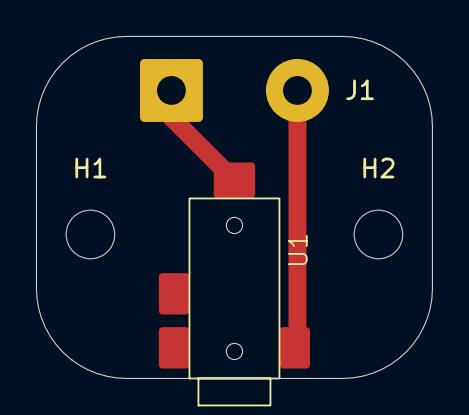
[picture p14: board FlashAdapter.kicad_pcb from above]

Board: 2 copper layers, 22.0 x 19.0 mm, 4 parts (0 on the bottom side), 2 nets.

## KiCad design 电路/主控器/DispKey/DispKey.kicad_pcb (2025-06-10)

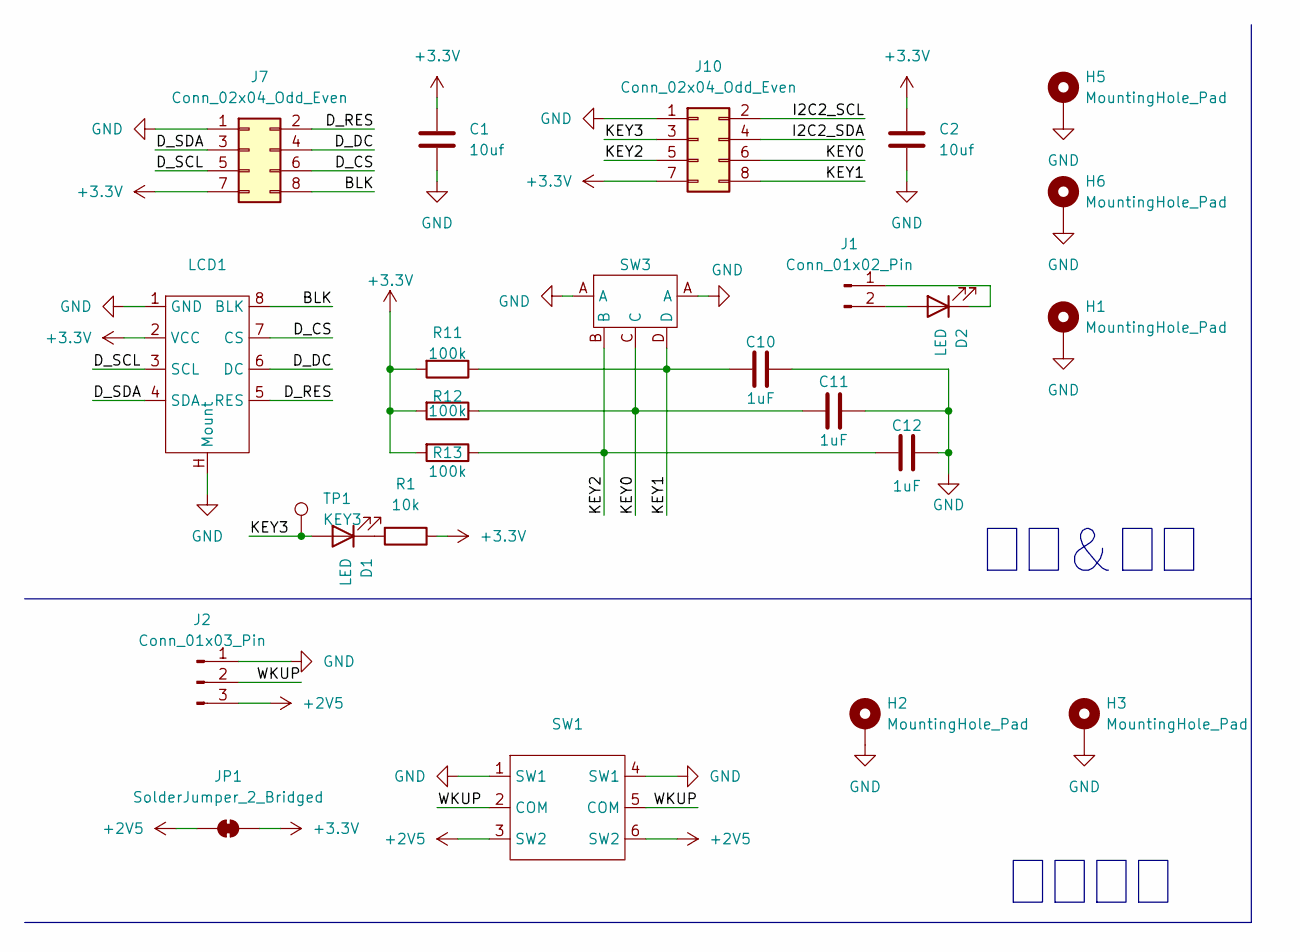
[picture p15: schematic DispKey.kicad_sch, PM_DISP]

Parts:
C1, C2: 10uf; C_0805_2012Metric_Pad1.18x1.45mm_HandSolder
C10, C11, C12: 1uF; C_0603_1608Metric_Pad1.08x0.95mm_HandSolder
D1, D2: LED; LED_0805_2012Metric_Pad1.15x1.40mm_HandSolder
H1: MountingHole_Pad; MountingHole_3.2mm_M3_DIN965_Pad
H2, H3, H5, H6: MountingHole_Pad; MountingHole_2.7mm_M2.5_DIN965_Pad
J1: Conn_01x02_Pin; SolderWire-0.1sqmm_1x02_P3.6mm_D0.4mm_OD1mm
J2: Conn_01x03_Pin; SolderWire-0.1sqmm_1x03_P3.6mm_D0.4mm_OD1mm
J7, J10: Conn_02x04_Odd_Even; PinHeader_2x04_P1.27mm_Vertical
JP1: SolderJumper_2_Bridged; SolderJumper-2_P1.3mm_Bridged2Bar_RoundedPad1.0x1.5mm
LCD1: LCD1.69_240_280
R1: 10k; R_0603_1608Metric_Pad0.98x0.95mm_HandSolder
R11, R12, R13: 100k; R_0603_1608Metric_Pad0.98x0.95mm_HandSolder
SW1: sw_push_5.8x5.8mm
SW3: Direction3 Pin5
TP1: KEY3; TestPoint_Pad_2.0x2.0mm

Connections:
+2V5: J2.3, JP1.1 (A), SW1.3 (SW2), SW1.6 (SW2)
+3.3V: C1.1, C2.1, J7.7, J10.7, JP1.2 (B), LCD1.2 (VCC), R1.1, R11.2, R12.2, R13.2
/BLK: J7.8, LCD1.8 (BLK)
/D_CS: J7.6, LCD1.7 (CS)
/D_DC: J7.4, LCD1.6 (DC)
/D_RES: J7.2, LCD1.5 (RES)
/D_SCL: J7.5, LCD1.3 (SCL)
/D_SDA: J7.3, LCD1.4 (SDA)
/I2C2_SCL: J10.2
/I2C2_SDA: J10.4
/KEY0: C11.1, J10.6, R12.1, SW3.C
/KEY1: C10.1, J10.8, R11.1, SW3.D
/KEY2: C12.1, J10.5, R13.1, SW3.B
/KEY3: D1.2 (A), J10.3, TP1.1
/WKUP: J2.2, SW1.2 (COM), SW1.5 (COM)
GND: C1.2, C2.2, C10.2, C11.2, C12.2, H1.1, H2.1, H3.1, H5.1, H6.1, J2.1, J7.1, J10.1, LCD1.1 (GND), LCD1.H (Mount), SW1.1 (SW1), SW1.4 (SW1), SW3.A
unnamed: D1.1 (K), R1.2
unnamed: D2.2 (A), J1.2
unnamed: D2.1 (K), J1.1

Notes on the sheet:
电源按键
显示&按键

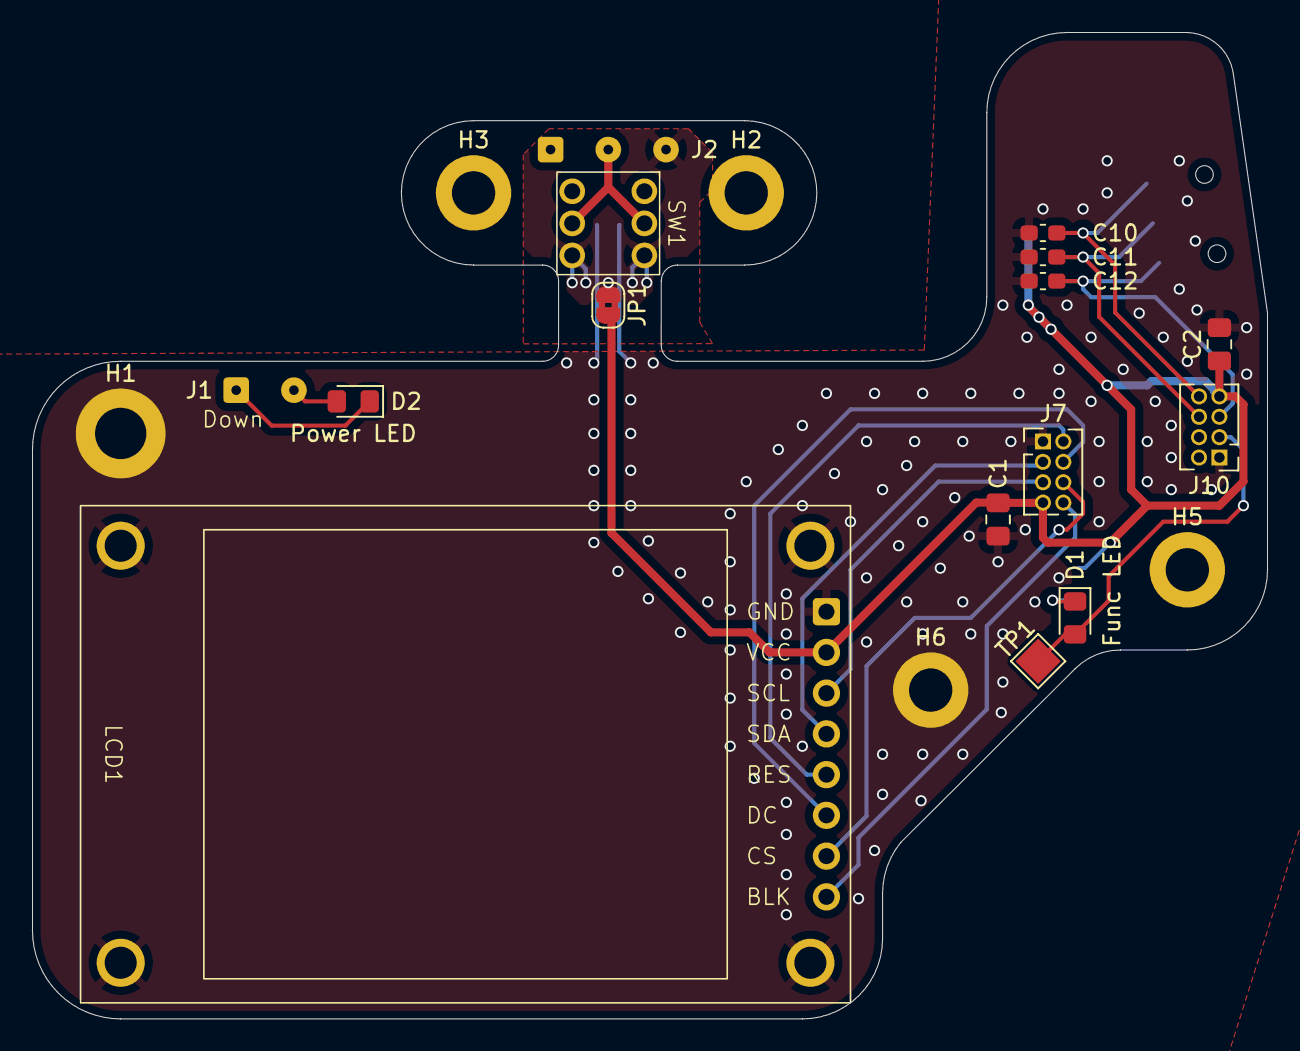
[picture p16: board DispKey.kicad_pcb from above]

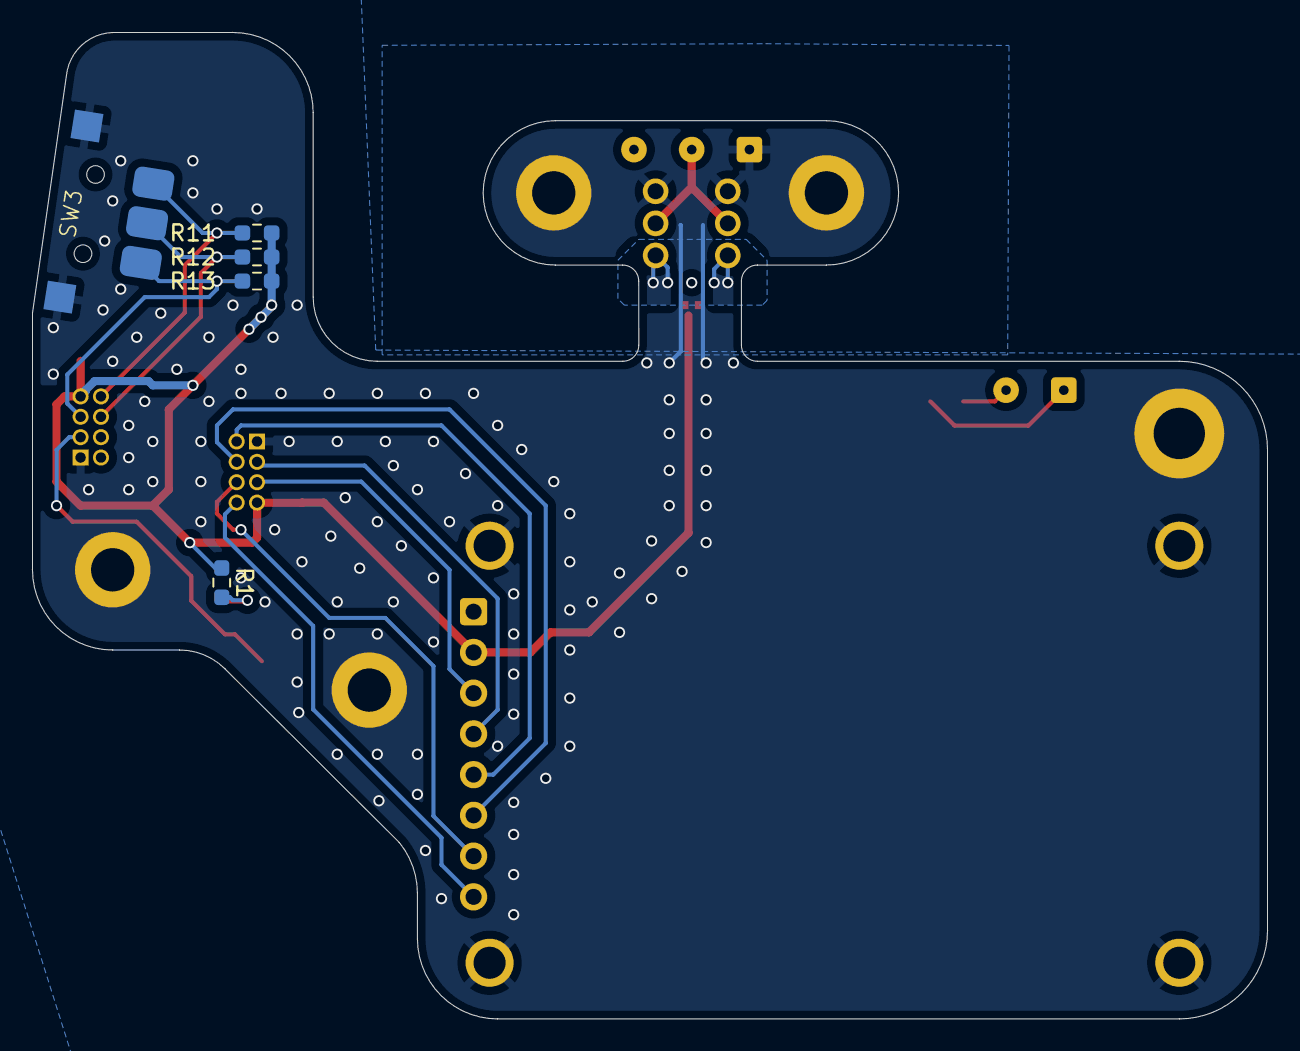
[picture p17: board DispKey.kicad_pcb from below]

Board: 2 copper layers, 77.0 x 61.5 mm, 25 parts (5 on the bottom side), 17 nets.

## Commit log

2025-06-23 ZUI init
    [PM_Controller.kicad_pcb, PM_Controller.kicad_sch, PM_Controller_Rev1_0.step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]
2025-06-29 电源显示ok
2025-07-01 吐片正常（废片测试）
2025-07-01 测距正常，下一步尽量改成用接收到idle，来防止误码。
2025-07-02 显示中加入核心以及PCB温度；后续应考虑测距使用接收到空闲中断避免误码导致中断。
2025-07-16 测距改成300ms一次，解决了测距卡死的问题
2025-07-16 修复定时器逻辑问题
2025-07-18 吐片后必须要重启电源才能测距
    [PM_Controller.kicad_sch]
2025-07-19 Rev1.0版本可正常工作
    [PM_Controller.kicad_pcb, PM_Controller.kicad_sch, PM_Controller1_1.step]
2025-09-27 第二代机械结构ok
    [1.69寸彩色TFT.SLDPRT, 1.6x14.6-拆机.SLDPRT, 1.6x14.6.SLDPRT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]
2025-11-23 闪关灯功能OK 准备给电机加一个斜坡
    [FlashAdapter.kicad_pcb, FlashAdapter.kicad_sch, FlashAdapter.step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]
2025-11-23 电机软起动加入，效果有限无法防止激光雷达下电
    [PM_Controller.kicad_sch]
2025-12-25 闪光灯ok
    [MamiyaPressLensSeat.SLDPRT, MamiyaPressLensSeat.STEP, PM_Controller.kicad_pcb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]
2026-01-05 闪光已经就绪，至此基本功能全部OK
    [吐片机构.SLDASM, 左侧壳.3mf, 左侧壳.SLDPRT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]
2026-01-05 清理仓库
2026-01-21 优化外壳与5V外部供电电路选择逻辑
    [PM_Controller.kicad_pcb, PM_Controller.kicad_sch, 吐片机构.SLDASM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]
2026-01-21 主控升级至Rev1.2，电机驱动 Rev1.1
    电机驱动修改后采用Mosfet控制高侧电源通路。主控配套进行了更改。
    [MotroDrive.kicad_pcb, MotroDrive.kicad_sch, PM_Controller.kicad_pcb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]
2026-02-02 更新了电机驱动以及主控器PCB
    [PM_Controller.kicad_pcb, bomR1.1.csv, bomR1.2.csv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]
2026-02-03 测试Rev1.2版本PCB，吐片导致测距停止问题已经修复
    测试Rev1.2版本PCB
    1. 原有引脚可以直接兼容G474芯片
    2. 吐片导致测距停止问题已经修复
    目前吐片的PWM加载方式可以进行调整
2026-02-03 硬件1.3版本，调整闪光灯为默认过MCU
    [PM_Controller.kicad_pcb, PM_Controller.kicad_sch]
2026-02-08 机械：优化吐片机械结构；代码：吐片电机及屏幕显示逻辑调整，ADC采样逻辑调整
    机械：
    1. 吐片下巴处增加导向齿轮
    代码：
    1. 电机启动斜坡加载速率调整
    2. 充电主控芯片采用外部供电时关闭屏幕及LED闪烁
    3. 电池ADC增加一阶低通滤波
    [MotroDrive.SLDASM, PH2x4.SLDPRT, 取片盒工具.3mf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]
2026-02-14 所有修改，两盒底片测试OK
    [片仓总成.SLDASM]
2026-02-27 新版本主片仓以及镜头机构设计，待测试
    主片仓与吐片钣金连接位置内移1.25mm；
    镜头机构重新设计连接机构，期望消除黑底；
    删除了结构吐片机构文件夹（内容早已合并入片仓总成，应删除）
    [1.6x14.6.SLDPRT, 1.6x20.6.SLDPRT, 1吐片钣金固定销.3mf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]
2026-02-27 修复对焦距离问题
    [MamiyaPressLensSeat.SLDPRT, 主片仓.SLDPRT, 内环.SLDPRT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]
2026-03-06 重新整理打印文件
    [MamiyaPressLensSeat.SLDPRT, MamiyaPressLensSeat.STL, PolaMiya_FullAssemble.3mf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]
2026-03-08 新版本PM，解决底部偏暗
    [PolaMiya_FullAssemble.3mf, 前侧.SLDPRT, 前侧.STL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]
2026-03-14 增加多种尺寸的齿轮定位
    [PolaMiya_FullAssemble.3mf, 装配.SLDASM, 镜头总成.SLDASM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]
2026-03-14 原本齿轮定位尺寸ok不应再加高度；修改电机驱动电路，但是电机驱动电路未完全ok
    [MotroDrive.kicad_pcb, MotroDrive.kicad_sch, PolaMiya_FullAssemble.3mf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]
2026-03-14 驱动电路升级至R1.2 未验证
    R1.2 升压二极管改为SS34；储能电容改为连接原始电源GND；电路板改为单面布局
    [MotroDrive.kicad_pcb, MotroDrive.kicad_sch]
2026-03-19 开始设计全息取景器
    [主座.SLDPRT, 主座.STL, 右侧板.STEP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]
2026-03-19 结构CNC条件具备，尚未调整螺纹孔
    [右侧板.SLDPRT, 右侧板.STEP, 左侧板.SLDPRT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]
2026-03-20 升级 Keil 6 (CMSIS) 项目配置
    - 添加 CMSIS 配置文件 (.cmsis/, *.cproject.yml, *.csolution.yml 等)
    - 添加 vcpkg 和 clangd 配置
    - 更新 .gitignore 忽略 log 文件
    - 更新 VS Code 配置
    [片仓总成.SLDASM, 装配.SLDASM, 镜头总成.SLDASM]
2026-03-20 更新 README，添加代码仓库链接
2026-03-20 将代码仓库链接移到 README 顶部
2026-03-21 更新许可证和说明文档
    - LICENSE.md: 移除子目录 LICENSE，统一使用 CERN-OHL-P-2.0，添加「除非另有说明」条款
    - ReadMe.md: 更新为硬件仓库专用说明，参考软件仓库格式
    - 删除 电路/LICENSE.md 和 结构 Rev2N/LICENSE.md
